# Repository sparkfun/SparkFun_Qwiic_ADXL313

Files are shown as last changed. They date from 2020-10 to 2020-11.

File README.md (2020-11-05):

SparkFun 3-Axis Digital Accelerometer Breakout - ADXL313 (Qwiic)
========================================

SparkFun 3-Axis Digital Accelerometer Breakout - ADXL313 (Qwiic) (https://www.sparkfun.com/products/17241)

[*SparkFun 3-Axis Digital Accelerometer Breakout - ADXL313 (Qwiic) (SEN-17241)*](https://www.sparkfun.com/products/17241)

The ADXL313 is a low power, high resolution (up to 13-bits) 3-axis accelerometer for measurement up to ±4g. It measures the static acceleration of gravity in tilt-sensing applications, as well as dynamic acceleration resulting from motion or shock. Digital output data is formatted as 16-bit twos complement and is accessible through the on board Qwiic connectors (I<sup>2</sup>C) or SPI. Its high resolution and low noise enable resolution of inclination changes of as little as 0.1°, while a built-in FIFO facilitates using oversampling techniques to improve resolution to as little as 0.025° of inclination. The integrated 32-level FIFO can also be used to store data to minimize host processor intervention, resulting in reduced system power consumption. Additional low power modes enable intelligent motion-based power management with threshold sensing and active acceleration measurement at extremely low power dissipation. 

Getting the ADXL313 Qwiic breakout set-up is easy. Simply supply the accelerometer with power and communication via the Qwiic connector to your chosen Qwiic development board and you will be good to go. Example use cases for the ADXL313 from Analog Devices include car alarm, hill start aid (HSA) systems, electronic parking brakes, and data recorders applications  (black boxes).

Repository Contents
-------------------

* **/Hardware** - Eagle design files (.brd, .sch)
* **/Hardware/Production** - Production panel files (.brd)

Documentation
--------------
* **[Hookup Guide](https://learn.sparkfun.com/tutorials/sparkfun-qwiic-3-axis-accelerometer-adxl313-hookup-guide)** - Hookup guide for the SparkFun Qwiic 3-Axis Accelerometer (ADXL313)
* **[Product Repository](https://github.com/sparkfun/SparkFun_Qwiic_ADXL313)** - Main hardware repository (including schematic and board design files)

Product Versions
----------------
* [SEN-17241](https://www.sparkfun.com/products/17241)- v1.0, Initial Release

License Information
-------------------

This product is _**open source**_! 

Please review the LICENSE.md file for license information. 

If you have any questions or concerns on licensing, please contact technical support on our [SparkFun forums](https://forum.sparkfun.com/viewforum.php?f=152).

Distributed as-is; no warranty is given.

- Your friends at SparkFun.

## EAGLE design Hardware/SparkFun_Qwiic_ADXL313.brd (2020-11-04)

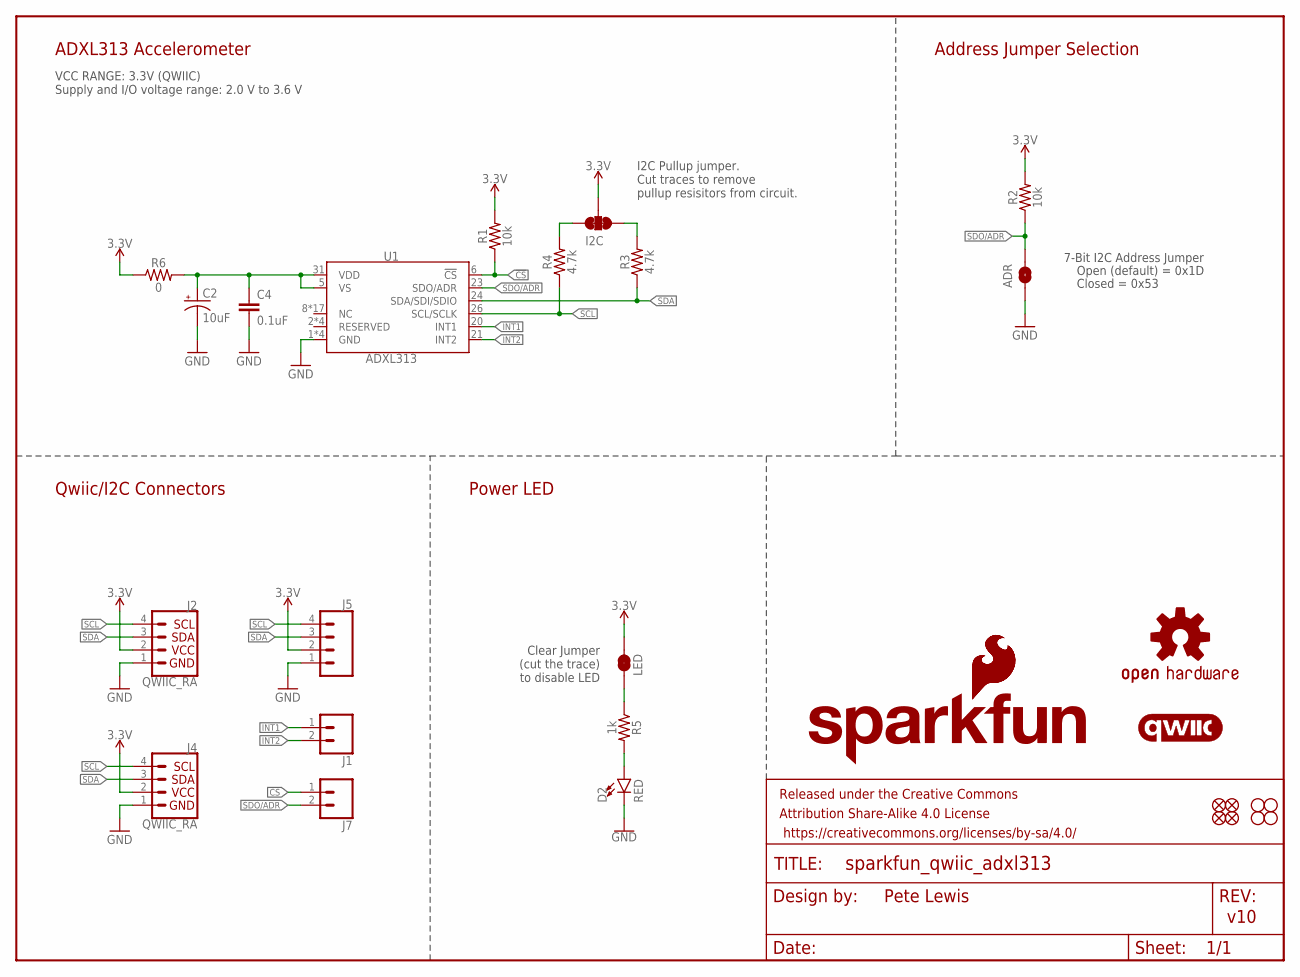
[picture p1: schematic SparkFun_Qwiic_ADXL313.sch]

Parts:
ADR: JUMPER-SMT_2_NO_SILK; SMT-JUMPER_2_NO_SILK
C2: 10uF; EIA3216
C4: 0.1uF; 0603
D2: RED; LED-0603
FRAME1: FRAME-LETTER; CREATIVE_COMMONS
I2C: JUMPER-SMT_3_2-NC_TRACE_SILK; SMT-JUMPER_3_2-NC_TRACE_SILK
J1, J7: CONN_021X02_NO_SILK; 1X02_NO_SILK
J2, J4: QWIIC_RA; JST04_1MM_RA
J5: CONN_041X04_NO_SILK; 1X04_NO_SILK
JP1: LED; SMT-JUMPER_2_NC_TRACE_SILK
JP2, JP5, JP6, JP11: FIDUCIALUFIDUCIAL; MICRO-FIDUCIAL
JP3, JP4, JP8, JP9: STAND-OFF
LOGO1: OSHW-LOGOMINI; OSHW-LOGO-MINI
LOGO2: SFE_LOGO_NAME_FLAME.1_INCH; SFE_LOGO_NAME_FLAME_.1
LOGO3: SFE_LOGO_FLAME.1_INCH; SFE_LOGO_FLAME_.1
LOGO4: QWIIC_LOGO_5MM; QWIIC_5MM
R1, R2: 10k; 0603
R3, R4: 4.7k; 0603
R5: 1k; 0603
R6: 0; 0603
U1: ADXL313; LFCSP

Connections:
3.3V: I2C.2, J2.2, J4.2, J5.2, JP1.2, R1.2, R2.2, R6.1
!CS: J7.1, R1.1, U1.6 (!CS)
GND: ADR.1, C2.C (-), C4.2, D2.C, J2.1, J4.1, J5.1, U1.1 (GND), U1.3 (GND), U1.4 (GND), U1.EPAD (GND)
INT1: J1.1, U1.20 (INT1)
INT2: J1.2, U1.21 (INT2)
unnamed: I2C.1, R3.2
unnamed: I2C.3, R4.2
unnamed: C2.A (+), C4.1, R6.2, U1.5 (VS), U1.31 (VDD)
unnamed: D2.A, R5.2
unnamed: JP1.1, R5.1
SCL: J2.4, J4.4, J5.4, R4.1, U1.26 (SCL/SCLK)
SDA: J2.3, J4.3, J5.3, R3.1, U1.24 (SDA/SDI/SDIO)
SDO/ADR: ADR.2, J7.2, R2.1, U1.23 (SDO/ADR)

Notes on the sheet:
7-Bit I2C Address Jumper
Closed = 0x53
Open (default) = 0x1D
Pete Lewis
v10
ADXL313 Accelerometer
Qwiic/I2C Connectors
I2C Pullup jumper. Cut traces to remove pullup resisitors from circuit.
Clear Jumper (cut the trace) to disable LED
Power LED
Address Jumper Selection
VCC RANGE: 3.3V (QWIIC) Supply and I/O voltage range: 2.0 V to 3.6 V

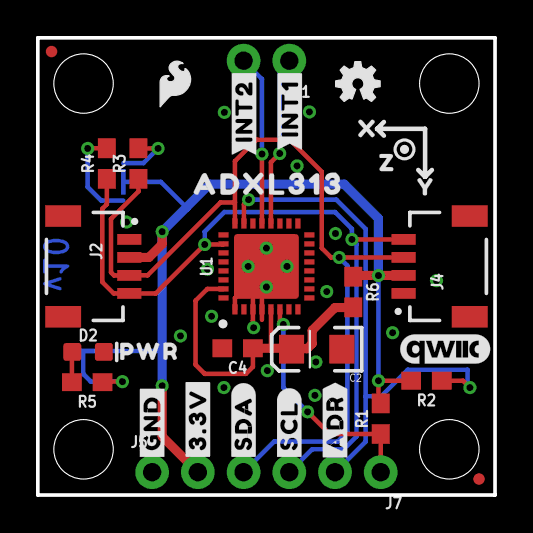
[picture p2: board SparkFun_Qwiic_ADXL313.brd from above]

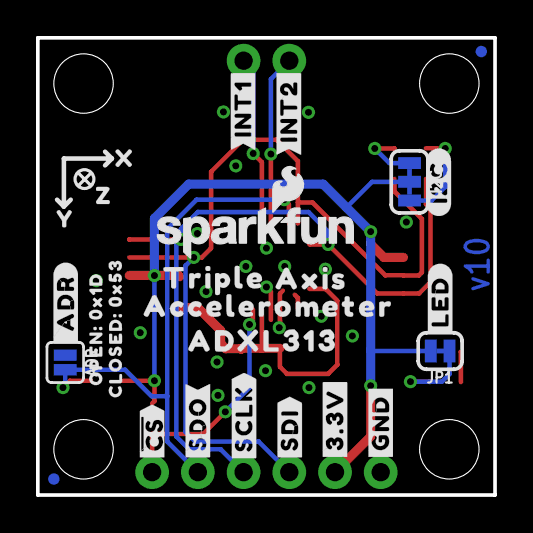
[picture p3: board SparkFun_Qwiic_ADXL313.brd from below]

Board: 2 copper layers, 25.4 x 25.4 mm, 63 parts (26 on the bottom side), 13 nets.

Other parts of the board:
U$1: TRIPLE0
U$2: AXIS0
U$3: ACCELEROMETER0
U$4, U$19: ADXL3130
U$5, U$6: #GND#0
U$7, U$8: #3#3V#0
U$9: #SDA#0
U$10: #SDI#0
U$11: #SCL#0
U$12: #_ADR#0
U$13, U$14: #INT2#0
U$15, U$16: #INT1#0
U$17, U$21: X0
U$18: ##CS##0
U$20: #SCLK#0
U$22: OPEN#_0X1D0
U$23: CLOSED#_0X530
U$24: #LED#0
U$25: PWR0
U$26, U$29: Y0
U$27: #I2C#0
U$28: #ADR#0
U$30: #SDO#0
U$31, U$32: Z0

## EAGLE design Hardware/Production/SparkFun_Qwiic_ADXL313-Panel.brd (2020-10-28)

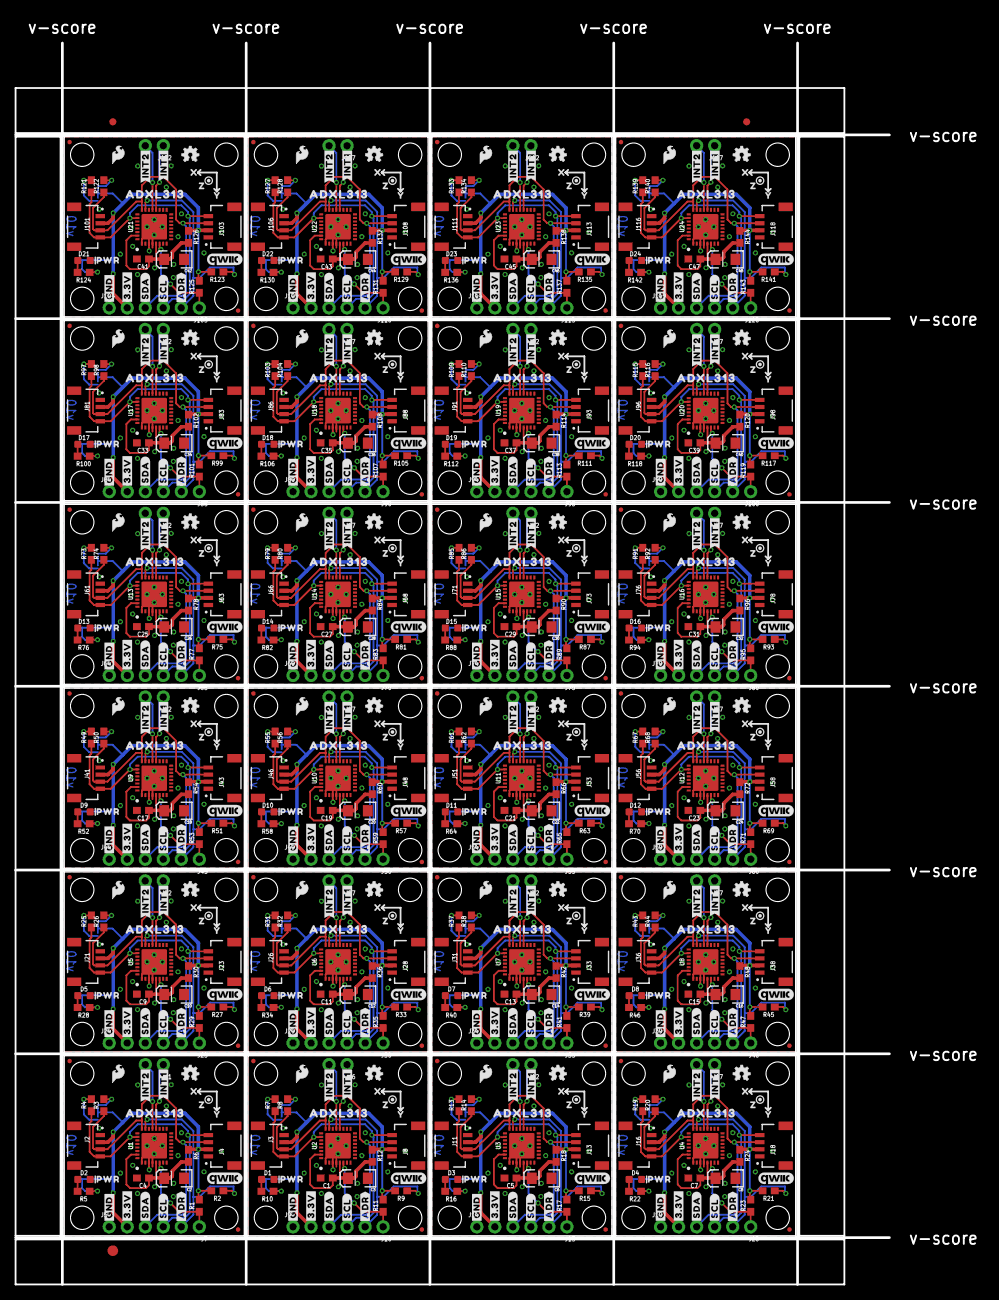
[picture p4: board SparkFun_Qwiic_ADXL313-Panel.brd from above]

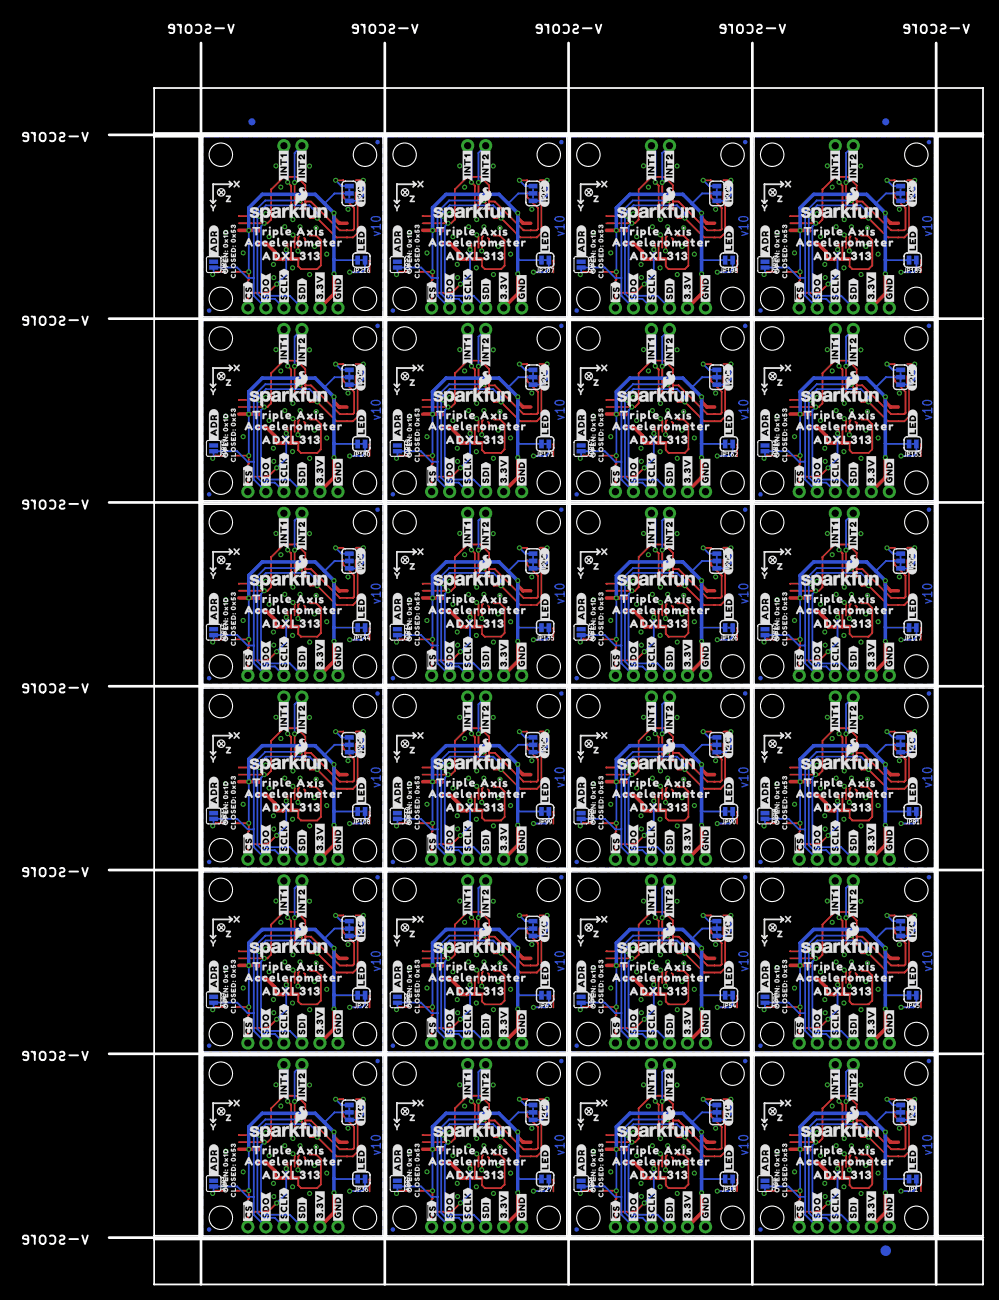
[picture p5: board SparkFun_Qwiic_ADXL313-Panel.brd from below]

Board: 2 copper layers, 123.2 x 175.0 mm, 1494 parts (627 on the bottom side), 312 nets.

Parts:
ADR, ADR1, ADR2, ADR3, ADR4, ADR5, ADR6, ADR7, ADR8, ADR9, ADR10, ADR11, ADR12, ADR13, ADR14, ADR15, ADR16, ADR17, ADR18, ADR19, ADR20, ADR21, ADR22, ADR23: SMT-JUMPER_2_NO_SILK
C1, C4, C5, C7, C9, C11, C13, C15, C17, C19, C21, C23, C25, C27, C29, C31, C33, C35, C37, C39, C41, C43, C45, C47: 0.1uF; 0603
C2, C3, C6, C8, C10, C12, C14, C16, C18, C20, C22, C24, C26, C28, C30, C32, C34, C36, C38, C40, C42, C44, C46, C48: 10uF; EIA3216
D1, D2, D3, D4, D5, D6, D7, D8, D9, D10, D11, D12, D13, D14, D15, D16, D17, D18, D19, D20, D21, D22, D23, D24: RED; LED-0603
E$1, E$2, E$3, E$4: FIDUCIAL-1X2
E$5, E$6: FIDUCIAL-1.5X3
I2C, I2C1, I2C2, I2C3, I2C4, I2C5, I2C6, I2C7, I2C8, I2C9, I2C10, I2C11, I2C12, I2C13, I2C14, I2C15, I2C16, I2C17, I2C18, I2C19, I2C20, I2C21, I2C22, I2C23: SMT-JUMPER_3_2-NC_TRACE_SILK
J1, J6, J7, J10, J12, J15, J17, J20, J22, J25, J27, J30, J32, J35, J37, J40, J42, J45, J47, J50, J52, J55, J57, J60, J62, J65, J67, J70, J72, J75, J77, J80, J82, J85, J87, J90, J92, J95, J97, J100, J102, J105, J107, J110, J112, J115, J117, J120: 1X02_NO_SILK
J2, J3, J4, J8, J11, J13, J16, J18, J21, J23, J26, J28, J31, J33, J36, J38, J41, J43, J46, J48, J51, J53, J56, J58, J61, J63, J66, J68, J71, J73, J76, J78, J81, J83, J86, J88, J91, J93, J96, J98, J101, J103, J106, J108, J111, J113, J116, J118: QWIIC_RA; JST04_1MM_RA
J5, J9, J14, J19, J24, J29, J34, J39, J44, J49, J54, J59, J64, J69, J74, J79, J84, J89, J94, J99, J104, J109, J114, J119: 1X04_NO_SILK
JP1, JP18, JP27, JP36, JP45, JP54, JP63, JP72, JP81, JP90, JP99, JP108, JP117, JP126, JP135, JP144, JP153, JP162, JP171, JP180, JP189, JP198, JP207, JP216: LED; SMT-JUMPER_2_NC_TRACE_SILK
JP2, JP5, JP6, JP11, JP12, JP13, JP14, JP15, JP21, JP22, JP23, JP24, JP30, JP31, JP32, JP33, JP39, JP40, JP41, JP42, JP48, JP49, JP50, JP51, JP57, JP58, JP59, JP60, JP66, JP67, JP68, JP69, JP75, JP76, JP77, JP78, JP84, JP85, JP86, JP87, JP93, JP94, JP95, JP96, JP102, JP103, JP104, JP105, JP111, JP112, JP113, JP114, JP120, JP121, JP122, JP123, JP129, JP130, JP131, JP132, JP138, JP139, JP140, JP141, JP147, JP148, JP149, JP150, JP156, JP157, JP158, JP159, JP165, JP166, JP167, JP168, JP174, JP175, JP176, JP177, JP183, JP184, JP185, JP186, JP192, JP193, JP194, JP195, JP201, JP202, JP203, JP204, JP210, JP211, JP212, JP213: FIDUCIALUFIDUCIAL; MICRO-FIDUCIAL
JP3, JP4, JP7, JP8, JP9, JP10, JP16, JP17, JP19, JP20, JP25, JP26, JP28, JP29, JP34, JP35, JP37, JP38, JP43, JP44, JP46, JP47, JP52, JP53, JP55, JP56, JP61, JP62, JP64, JP65, JP70, JP71, JP73, JP74, JP79, JP80, JP82, JP83, JP88, JP89, JP91, JP92, JP97, JP98, JP100, JP101, JP106, JP107, JP109, JP110, JP115, JP116, JP118, JP119, JP124, JP125, JP127, JP128, JP133, JP134, JP136, JP137, JP142, JP143, JP145, JP146, JP151, JP152, JP154, JP155, JP160, JP161, JP163, JP164, JP169, JP170, JP172, JP173, JP178, JP179, JP181, JP182, JP187, JP188, JP190, JP191, JP196, JP197, JP199, JP200, JP205, JP206, JP208, JP209, JP214, JP215: STAND-OFF
LOGO1, LOGO5, LOGO9, LOGO13, LOGO17, LOGO21, LOGO25, LOGO29, LOGO33, LOGO37, LOGO41, LOGO45, LOGO49, LOGO53, LOGO57, LOGO61, LOGO65, LOGO69, LOGO73, LOGO77, LOGO81, LOGO85, LOGO89, LOGO93: OSHW-LOGOMINI; OSHW-LOGO-MINI
LOGO2, LOGO6, LOGO10, LOGO14, LOGO18, LOGO22, LOGO26, LOGO30, LOGO34, LOGO38, LOGO42, LOGO46, LOGO50, LOGO54, LOGO58, LOGO62, LOGO66, LOGO70, LOGO74, LOGO78, LOGO82, LOGO86, LOGO90, LOGO94: SFE_LOGO_NAME_FLAME.1_INCH; SFE_LOGO_NAME_FLAME_.1
LOGO3, LOGO8, LOGO12, LOGO16, LOGO20, LOGO24, LOGO28, LOGO32, LOGO36, LOGO40, LOGO44, LOGO48, LOGO52, LOGO56, LOGO60, LOGO64, LOGO68, LOGO72, LOGO76, LOGO80, LOGO84, LOGO88, LOGO92, LOGO96: SFE_LOGO_FLAME.1_INCH; SFE_LOGO_FLAME_.1
LOGO4, LOGO7, LOGO11, LOGO15, LOGO19, LOGO23, LOGO27, LOGO31, LOGO35, LOGO39, LOGO43, LOGO47, LOGO51, LOGO55, LOGO59, LOGO63, LOGO67, LOGO71, LOGO75, LOGO79, LOGO83, LOGO87, LOGO91, LOGO95: QWIIC_LOGO_5MM; QWIIC_5MM
R1, R2, R9, R11, R15, R17, R21, R23, R27, R29, R33, R35, R39, R41, R45, R47, R51, R53, R57, R59, R63, R65, R69, R71, R75, R77, R81, R83, R87, R89, R93, R95, R99, R101, R105, R107, R111, R113, R117, R119, R123, R125, R129, R131, R135, R137, R141, R143: 10k; 0603
R3, R4, R7, R8, R13, R14, R19, R20, R25, R26, R31, R32, R37, R38, R43, R44, R49, R50, R55, R56, R61, R62, R67, R68, R73, R74, R79, R80, R85, R86, R91, R92, R97, R98, R103, R104, R109, R110, R115, R116, R121, R122, R127, R128, R133, R134, R139, R140: 4.7k; 0603
R5, R10, R16, R22, R28, R34, R40, R46, R52, R58, R64, R70, R76, R82, R88, R94, R100, R106, R112, R118, R124, R130, R136, R142: 1k; 0603
R6, R12, R18, R24, R30, R36, R42, R48, R54, R60, R66, R72, R78, R84, R90, R96, R102, R108, R114, R120, R126, R132, R138, R144: 0; 0603
U1, U2, U3, U4, U5, U6, U7, U8, U9, U10, U11, U12, U13, U14, U15, U16, U17, U18, U19, U20, U21, U22, U23, U24: ADXL313; LFCSP
U$1, U$33, U$65, U$97, U$129, U$161, U$193, U$225, U$257, U$289, U$321, U$353, U$385, U$417, U$449, U$481, U$513, U$545, U$577, U$609, U$641, U$673, U$705, U$737: TRIPLE0
U$2, U$34, U$66, U$98, U$130, U$162, U$194, U$226, U$258, U$290, U$322, U$354, U$386, U$418, U$450, U$482, U$514, U$546, U$578, U$610, U$642, U$674, U$706, U$738: AXIS0
U$3, U$35, U$67, U$99, U$131, U$163, U$195, U$227, U$259, U$291, U$323, U$355, U$387, U$419, U$451, U$483, U$515, U$547, U$579, U$611, U$643, U$675, U$707, U$739: ACCELEROMETER0
U$4, U$19, U$36, U$52, U$68, U$84, U$100, U$116, U$132, U$148, U$164, U$180, U$196, U$212, U$228, U$244, U$260, U$276, U$292, U$308, U$324, U$340, U$356, U$372, U$388, U$404, U$420, U$436, U$452, U$468, U$484, U$500, U$516, U$532, U$548, U$564, U$580, U$596, U$612, U$628, U$644, U$660, U$676, U$692, U$708, U$724, U$740, U$756: ADXL3130
U$5, U$6, U$37, U$38, U$69, U$70, U$101, U$102, U$133, U$134, U$165, U$166, U$197, U$198, U$229, U$230, U$261, U$262, U$293, U$294, U$325, U$326, U$357, U$358, U$389, U$390, U$421, U$422, U$453, U$454, U$485, U$486, U$517, U$518, U$549, U$550, U$581, U$582, U$613, U$614, U$645, U$646, U$677, U$678, U$709, U$710, U$741, U$742: #GND#0
U$7, U$8, U$39, U$40, U$71, U$72, U$103, U$104, U$135, U$136, U$167, U$168, U$199, U$200, U$231, U$232, U$263, U$264, U$295, U$296, U$327, U$328, U$359, U$360, U$391, U$392, U$423, U$424, U$455, U$456, U$487, U$488, U$519, U$520, U$551, U$552, U$583, U$584, U$615, U$616, U$647, U$648, U$679, U$680, U$711, U$712, U$743, U$744: #3#3V#0
U$9, U$41, U$73, U$105, U$137, U$169, U$201, U$233, U$265, U$297, U$329, U$361, U$393, U$425, U$457, U$489, U$521, U$553, U$585, U$617, U$649, U$681, U$713, U$745: #SDA#0
U$10, U$56, U$88, U$120, U$152, U$184, U$216, U$248, U$280, U$312, U$344, U$376, U$408, U$440, U$472, U$504, U$536, U$568, U$600, U$632, U$664, U$696, U$728, U$760: #SDI#0
U$11, U$42, U$74, U$106, U$138, U$170, U$202, U$234, U$266, U$298, U$330, U$362, U$394, U$426, U$458, U$490, U$522, U$554, U$586, U$618, U$650, U$682, U$714, U$746: #SCL#0
U$12, U$58, U$90, U$122, U$154, U$186, U$218, U$250, U$282, U$314, U$346, U$378, U$410, U$442, U$474, U$506, U$538, U$570, U$602, U$634, U$666, U$698, U$730, U$762: #_ADR#0
U$13, U$14, U$43, U$44, U$75, U$76, U$107, U$108, U$139, U$140, U$171, U$172, U$203, U$204, U$235, U$236, U$267, U$268, U$299, U$300, U$331, U$332, U$363, U$364, U$395, U$396, U$427, U$428, U$459, U$460, U$491, U$492, U$523, U$524, U$555, U$556, U$587, U$588, U$619, U$620, U$651, U$652, U$683, U$684, U$715, U$716, U$747, U$748: #INT2#0
U$15, U$16, U$45, U$46, U$77, U$78, U$109, U$110, U$141, U$142, U$173, U$174, U$205, U$206, U$237, U$238, U$269, U$270, U$301, U$302, U$333, U$334, U$365, U$366, U$397, U$398, U$429, U$430, U$461, U$462, U$493, U$494, U$525, U$526, U$557, U$558, U$589, U$590, U$621, U$622, U$653, U$654, U$685, U$686, U$717, U$718, U$749, U$750: #INT1#0
U$17, U$21, U$59, U$60, U$91, U$92, U$123, U$124, U$155, U$156, U$187, U$188, U$219, U$220, U$251, U$252, U$283, U$284, U$315, U$316, U$347, U$348, U$379, U$380, U$411, U$412, U$443, U$444, U$475, U$476, U$507, U$508, U$539, U$540, U$571, U$572, U$603, U$604, U$635, U$636, U$667, U$668, U$699, U$700, U$731, U$732, U$763, U$764: X0
U$18, U$47, U$79, U$111, U$143, U$175, U$207, U$239, U$271, U$303, U$335, U$367, U$399, U$431, U$463, U$495, U$527, U$559, U$591, U$623, U$655, U$687, U$719, U$751: ##CS##0
U$20, U$57, U$89, U$121, U$153, U$185, U$217, U$249, U$281, U$313, U$345, U$377, U$409, U$441, U$473, U$505, U$537, U$569, U$601, U$633, U$665, U$697, U$729, U$761: #SCLK#0
U$22, U$48, U$80, U$112, U$144, U$176, U$208, U$240, U$272, U$304, U$336, U$368, U$400, U$432, U$464, U$496, U$528, U$560, U$592, U$624, U$656, U$688, U$720, U$752: OPEN#_0X1D0
U$23, U$49, U$81, U$113, U$145, U$177, U$209, U$241, U$273, U$305, U$337, U$369, U$401, U$433, U$465, U$497, U$529, U$561, U$593, U$625, U$657, U$689, U$721, U$753: CLOSED#_0X530
U$24, U$50, U$82, U$114, U$146, U$178, U$210, U$242, U$274, U$306, U$338, U$370, U$402, U$434, U$466, U$498, U$530, U$562, U$594, U$626, U$658, U$690, U$722, U$754: #LED#0
U$25, U$51, U$83, U$115, U$147, U$179, U$211, U$243, U$275, U$307, U$339, U$371, U$403, U$435, U$467, U$499, U$531, U$563, U$595, U$627, U$659, U$691, U$723, U$755: PWR0
U$26, U$29, U$61, U$62, U$93, U$94, U$125, U$126, U$157, U$158, U$189, U$190, U$221, U$222, U$253, U$254, U$285, U$286, U$317, U$318, U$349, U$350, U$381, U$382, U$413, U$414, U$445, U$446, U$477, U$478, U$509, U$510, U$541, U$542, U$573, U$574, U$605, U$606, U$637, U$638, U$669, U$670, U$701, U$702, U$733, U$734, U$765, U$766: Y0
U$27, U$53, U$85, U$117, U$149, U$181, U$213, U$245, U$277, U$309, U$341, U$373, U$405, U$437, U$469, U$501, U$533, U$565, U$597, U$629, U$661, U$693, U$725, U$757: #I2C#0
U$28, U$55, U$87, U$119, U$151, U$183, U$215, U$247, U$279, U$311, U$343, U$375, U$407, U$439, U$471, U$503, U$535, U$567, U$599, U$631, U$663, U$695, U$727, U$759: #ADR#0
U$30, U$54, U$86, U$118, U$150, U$182, U$214, U$246, U$278, U$310, U$342, U$374, U$406, U$438, U$470, U$502, U$534, U$566, U$598, U$630, U$662, U$694, U$726, U$758: #SDO#0
U$31, U$32, U$63, U$64, U$95, U$96, U$127, U$128, U$159, U$160, U$191, U$192, U$223, U$224, U$255, U$256, U$287, U$288, U$319, U$320, U$351, U$352, U$383, U$384, U$415, U$416, U$447, U$448, U$479, U$480, U$511, U$512, U$543, U$544, U$575, U$576, U$607, U$608, U$639, U$640, U$671, U$672, U$703, U$704, U$735, U$736, U$767, U$768: Z0

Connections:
3.3V: I2C.2, J2.2, J4.2, J5.2, JP1.2, R1.2, R2.2, R6.1
3.3V1: I2C1.2, J3.2, J8.2, J9.2, JP18.2, R9.2, R11.2, R12.1
3.3V2: I2C2.2, J11.2, J13.2, J14.2, JP27.2, R15.2, R17.2, R18.1
3.3V3: I2C3.2, J16.2, J18.2, J19.2, JP36.2, R21.2, R23.2, R24.1
3.3V4: I2C4.2, J21.2, J23.2, J24.2, JP45.2, R27.2, R29.2, R30.1
3.3V5: I2C5.2, J26.2, J28.2, J29.2, JP54.2, R33.2, R35.2, R36.1
3.3V6: I2C6.2, J31.2, J33.2, J34.2, JP63.2, R39.2, R41.2, R42.1
3.3V7: I2C7.2, J36.2, J38.2, J39.2, JP72.2, R45.2, R47.2, R48.1
3.3V8: I2C8.2, J41.2, J43.2, J44.2, JP81.2, R51.2, R53.2, R54.1
3.3V9: I2C9.2, J46.2, J48.2, J49.2, JP90.2, R57.2, R59.2, R60.1
3.3V10: I2C10.2, J51.2, J53.2, J54.2, JP99.2, R63.2, R65.2, R66.1
3.3V11: I2C11.2, J56.2, J58.2, J59.2, JP108.2, R69.2, R71.2, R72.1
3.3V12: I2C12.2, J61.2, J63.2, J64.2, JP117.2, R75.2, R77.2, R78.1
3.3V13: I2C13.2, J66.2, J68.2, J69.2, JP126.2, R81.2, R83.2, R84.1
3.3V14: I2C14.2, J71.2, J73.2, J74.2, JP135.2, R87.2, R89.2, R90.1
3.3V15: I2C15.2, J76.2, J78.2, J79.2, JP144.2, R93.2, R95.2, R96.1
3.3V16: I2C16.2, J81.2, J83.2, J84.2, JP153.2, R99.2, R101.2, R102.1
3.3V17: I2C17.2, J86.2, J88.2, J89.2, JP162.2, R105.2, R107.2, R108.1
3.3V18: I2C18.2, J91.2, J93.2, J94.2, JP171.2, R111.2, R113.2, R114.1
3.3V19: I2C19.2, J96.2, J98.2, J99.2, JP180.2, R117.2, R119.2, R120.1
3.3V20: I2C20.2, J101.2, J103.2, J104.2, JP189.2, R123.2, R125.2, R126.1
3.3V21: I2C21.2, J106.2, J108.2, J109.2, JP198.2, R129.2, R131.2, R132.1
3.3V22: I2C22.2, J111.2, J113.2, J114.2, JP207.2, R135.2, R137.2, R138.1
3.3V23: I2C23.2, J116.2, J118.2, J119.2, JP216.2, R141.2, R143.2, R144.1
!CS: J7.1, R1.1, U1.6
!CS1: J10.1, R11.1, U2.6
!CS2: J15.1, R17.1, U3.6
!CS3: J20.1, R23.1, U4.6
!CS4: J25.1, R29.1, U5.6
!CS5: J30.1, R35.1, U6.6
!CS6: J35.1, R41.1, U7.6
!CS7: J40.1, R47.1, U8.6
!CS8: J45.1, R53.1, U9.6
!CS9: J50.1, R59.1, U10.6
!CS10: J55.1, R65.1, U11.6
!CS11: J60.1, R71.1, U12.6
!CS12: J65.1, R77.1, U13.6
!CS13: J70.1, R83.1, U14.6
!CS14: J75.1, R89.1, U15.6
!CS15: J80.1, R95.1, U16.6
!CS16: J85.1, R101.1, U17.6
!CS17: J90.1, R107.1, U18.6
!CS18: J95.1, R113.1, U19.6
!CS19: J100.1, R119.1, U20.6
!CS20: J105.1, R125.1, U21.6
!CS21: J110.1, R131.1, U22.6
!CS22: J115.1, R137.1, U23.6
!CS23: J120.1, R143.1, U24.6
GND: ADR.1, C2.C, C4.2, D2.C, J2.1, J4.1, J5.1, U1.1, U1.3, U1.4, U1.EPAD
GND1: ADR1.1, C1.2, C3.C, D1.C, J3.1, J8.1, J9.1, U2.1, U2.3, U2.4, U2.EPAD
GND2: ADR2.1, C5.2, C6.C, D3.C, J11.1, J13.1, J14.1, U3.1, U3.3, U3.4, U3.EPAD
GND3: ADR3.1, C7.2, C8.C, D4.C, J16.1, J18.1, J19.1, U4.1, U4.3, U4.4, U4.EPAD
GND4: ADR4.1, C9.2, C10.C, D5.C, J21.1, J23.1, J24.1, U5.1, U5.3, U5.4, U5.EPAD
GND5: ADR5.1, C11.2, C12.C, D6.C, J26.1, J28.1, J29.1, U6.1, U6.3, U6.4, U6.EPAD
GND6: ADR6.1, C13.2, C14.C, D7.C, J31.1, J33.1, J34.1, U7.1, U7.3, U7.4, U7.EPAD
GND7: ADR7.1, C15.2, C16.C, D8.C, J36.1, J38.1, J39.1, U8.1, U8.3, U8.4, U8.EPAD
GND8: ADR8.1, C17.2, C18.C, D9.C, J41.1, J43.1, J44.1, U9.1, U9.3, U9.4, U9.EPAD
GND9: ADR9.1, C19.2, C20.C, D10.C, J46.1, J48.1, J49.1, U10.1, U10.3, U10.4, U10.EPAD
GND10: ADR10.1, C21.2, C22.C, D11.C, J51.1, J53.1, J54.1, U11.1, U11.3, U11.4, U11.EPAD
GND11: ADR11.1, C23.2, C24.C, D12.C, J56.1, J58.1, J59.1, U12.1, U12.3, U12.4, U12.EPAD
GND12: ADR12.1, C25.2, C26.C, D13.C, J61.1, J63.1, J64.1, U13.1, U13.3, U13.4, U13.EPAD
GND13: ADR13.1, C27.2, C28.C, D14.C, J66.1, J68.1, J69.1, U14.1, U14.3, U14.4, U14.EPAD
GND14: ADR14.1, C29.2, C30.C, D15.C, J71.1, J73.1, J74.1, U15.1, U15.3, U15.4, U15.EPAD
GND15: ADR15.1, C31.2, C32.C, D16.C, J76.1, J78.1, J79.1, U16.1, U16.3, U16.4, U16.EPAD
GND16: ADR16.1, C33.2, C34.C, D17.C, J81.1, J83.1, J84.1, U17.1, U17.3, U17.4, U17.EPAD
GND17: ADR17.1, C35.2, C36.C, D18.C, J86.1, J88.1, J89.1, U18.1, U18.3, U18.4, U18.EPAD
GND18: ADR18.1, C37.2, C38.C, D19.C, J91.1, J93.1, J94.1, U19.1, U19.3, U19.4, U19.EPAD
GND19: ADR19.1, C39.2, C40.C, D20.C, J96.1, J98.1, J99.1, U20.1, U20.3, U20.4, U20.EPAD
GND20: ADR20.1, C41.2, C42.C, D21.C, J101.1, J103.1, J104.1, U21.1, U21.3, U21.4, U21.EPAD
GND21: ADR21.1, C43.2, C44.C, D22.C, J106.1, J108.1, J109.1, U22.1, U22.3, U22.4, U22.EPAD
GND22: ADR22.1, C45.2, C46.C, D23.C, J111.1, J113.1, J114.1, U23.1, U23.3, U23.4, U23.EPAD
GND23: ADR23.1, C47.2, C48.C, D24.C, J116.1, J118.1, J119.1, U24.1, U24.3, U24.4, U24.EPAD
INT1: J1.1, U1.20
INT2: J1.2, U1.21
INT3: J6.2, U2.21
INT4: J6.1, U2.20
INT5: J12.2, U3.21
INT6: J12.1, U3.20
INT7: J17.2, U4.21
INT8: J17.1, U4.20
INT9: J22.2, U5.21
INT10: J22.1, U5.20
INT11: J27.2, U6.21
INT12: J27.1, U6.20
INT13: J32.2, U7.21
INT14: J32.1, U7.20
INT15: J37.2, U8.21
INT16: J37.1, U8.20
INT17: J42.2, U9.21
INT18: J42.1, U9.20
INT19: J47.2, U10.21
INT20: J47.1, U10.20
INT21: J52.2, U11.21
INT22: J52.1, U11.20
INT23: J57.2, U12.21
INT24: J57.1, U12.20
INT25: J62.2, U13.21
INT26: J62.1, U13.20
INT27: J67.2, U14.21
INT28: J67.1, U14.20
INT29: J72.2, U15.21
INT30: J72.1, U15.20
INT31: J77.2, U16.21
INT32: J77.1, U16.20
INT33: J82.2, U17.21
INT34: J82.1, U17.20
INT35: J87.2, U18.21
INT36: J87.1, U18.20
INT37: J92.2, U19.21
INT38: J92.1, U19.20
INT39: J97.2, U20.21
INT40: J97.1, U20.20
INT41: J102.2, U21.21
INT42: J102.1, U21.20
INT43: J107.2, U22.21
INT44: J107.1, U22.20
INT45: J112.2, U23.21
INT46: J112.1, U23.20
INT47: J117.2, U24.21
INT48: J117.1, U24.20
unnamed: I2C.1, R3.2
unnamed: I2C.3, R4.2
unnamed: C2.A, C4.1, R6.2, U1.5, U1.31
unnamed: I2C1.1, R8.2
unnamed: I2C1.3, R7.2
unnamed: D2.A, R5.2
unnamed: D1.A, R10.2
unnamed: JP1.1, R5.1
unnamed: JP18.1, R10.1
unnamed: C1.1, C3.A, R12.2, U2.5, U2.31
unnamed: I2C2.1, R14.2
unnamed: I2C2.3, R13.2
unnamed: D3.A, R16.2
unnamed: JP27.1, R16.1
unnamed: C5.1, C6.A, R18.2, U3.5, U3.31
unnamed: I2C3.1, R20.2
unnamed: I2C3.3, R19.2
unnamed: D4.A, R22.2
unnamed: JP36.1, R22.1
unnamed: C7.1, C8.A, R24.2, U4.5, U4.31
unnamed: I2C4.1, R26.2
unnamed: I2C4.3, R25.2
unnamed: D5.A, R28.2
unnamed: JP45.1, R28.1
unnamed: C9.1, C10.A, R30.2, U5.5, U5.31
unnamed: I2C5.1, R32.2
unnamed: I2C5.3, R31.2
unnamed: D6.A, R34.2
unnamed: JP54.1, R34.1
unnamed: C11.1, C12.A, R36.2, U6.5, U6.31
unnamed: I2C6.1, R38.2
unnamed: I2C6.3, R37.2
unnamed: D7.A, R40.2
unnamed: JP63.1, R40.1
unnamed: C13.1, C14.A, R42.2, U7.5, U7.31
unnamed: I2C7.1, R44.2
unnamed: I2C7.3, R43.2
unnamed: D8.A, R46.2
unnamed: JP72.1, R46.1
unnamed: C15.1, C16.A, R48.2, U8.5, U8.31
unnamed: I2C8.1, R50.2
unnamed: I2C8.3, R49.2
unnamed: D9.A, R52.2
unnamed: JP81.1, R52.1
unnamed: C17.1, C18.A, R54.2, U9.5, U9.31
unnamed: I2C9.1, R56.2
unnamed: I2C9.3, R55.2
unnamed: D10.A, R58.2
unnamed: JP90.1, R58.1
unnamed: C19.1, C20.A, R60.2, U10.5, U10.31
unnamed: I2C10.1, R62.2
unnamed: I2C10.3, R61.2
unnamed: D11.A, R64.2
unnamed: JP99.1, R64.1
unnamed: C21.1, C22.A, R66.2, U11.5, U11.31
unnamed: I2C11.1, R68.2
unnamed: I2C11.3, R67.2
unnamed: D12.A, R70.2
unnamed: JP108.1, R70.1
unnamed: C23.1, C24.A, R72.2, U12.5, U12.31
unnamed: I2C12.1, R74.2
unnamed: I2C12.3, R73.2
unnamed: D13.A, R76.2
unnamed: JP117.1, R76.1
unnamed: C25.1, C26.A, R78.2, U13.5, U13.31
unnamed: I2C13.1, R80.2
unnamed: I2C13.3, R79.2
unnamed: D14.A, R82.2
unnamed: JP126.1, R82.1
unnamed: C27.1, C28.A, R84.2, U14.5, U14.31
unnamed: I2C14.1, R86.2
unnamed: I2C14.3, R85.2
unnamed: D15.A, R88.2
unnamed: JP135.1, R88.1
unnamed: C29.1, C30.A, R90.2, U15.5, U15.31
unnamed: I2C15.1, R92.2
unnamed: I2C15.3, R91.2
unnamed: D16.A, R94.2
unnamed: JP144.1, R94.1
unnamed: C31.1, C32.A, R96.2, U16.5, U16.31
unnamed: I2C16.1, R98.2
unnamed: I2C16.3, R97.2
unnamed: D17.A, R100.2
unnamed: JP153.1, R100.1
unnamed: C33.1, C34.A, R102.2, U17.5, U17.31
unnamed: I2C17.1, R104.2
unnamed: I2C17.3, R103.2
unnamed: D18.A, R106.2
unnamed: JP162.1, R106.1
unnamed: C35.1, C36.A, R108.2, U18.5, U18.31
unnamed: I2C18.1, R110.2
unnamed: I2C18.3, R109.2
unnamed: D19.A, R112.2
unnamed: JP171.1, R112.1
unnamed: C37.1, C38.A, R114.2, U19.5, U19.31
unnamed: I2C19.1, R116.2
unnamed: I2C19.3, R115.2
unnamed: D20.A, R118.2
unnamed: JP180.1, R118.1
unnamed: C39.1, C40.A, R120.2, U20.5, U20.31
unnamed: I2C20.1, R122.2
unnamed: I2C20.3, R121.2
unnamed: D21.A, R124.2
unnamed: JP189.1, R124.1
unnamed: C41.1, C42.A, R126.2, U21.5, U21.31
unnamed: I2C21.1, R128.2
unnamed: I2C21.3, R127.2
unnamed: D22.A, R130.2
unnamed: JP198.1, R130.1
unnamed: C43.1, C44.A, R132.2, U22.5, U22.31
unnamed: I2C22.1, R134.2
unnamed: I2C22.3, R133.2
unnamed: D23.A, R136.2
unnamed: JP207.1, R136.1
unnamed: C45.1, C46.A, R138.2, U23.5, U23.31
unnamed: I2C23.1, R140.2
unnamed: I2C23.3, R139.2
unnamed: D24.A, R142.2
unnamed: JP216.1, R142.1
unnamed: C47.1, C48.A, R144.2, U24.5, U24.31
SCL: J2.4, J4.4, J5.4, R4.1, U1.26
SCL1: J3.4, J8.4, J9.4, R7.1, U2.26
SCL2: J11.4, J13.4, J14.4, R13.1, U3.26
SCL3: J16.4, J18.4, J19.4, R19.1, U4.26
SCL4: J21.4, J23.4, J24.4, R25.1, U5.26
SCL5: J26.4, J28.4, J29.4, R31.1, U6.26
SCL6: J31.4, J33.4, J34.4, R37.1, U7.26
SCL7: J36.4, J38.4, J39.4, R43.1, U8.26
SCL8: J41.4, J43.4, J44.4, R49.1, U9.26
SCL9: J46.4, J48.4, J49.4, R55.1, U10.26
SCL10: J51.4, J53.4, J54.4, R61.1, U11.26
SCL11: J56.4, J58.4, J59.4, R67.1, U12.26
SCL12: J61.4, J63.4, J64.4, R73.1, U13.26
SCL13: J66.4, J68.4, J69.4, R79.1, U14.26
SCL14: J71.4, J73.4, J74.4, R85.1, U15.26
SCL15: J76.4, J78.4, J79.4, R91.1, U16.26
SCL16: J81.4, J83.4, J84.4, R97.1, U17.26
SCL17: J86.4, J88.4, J89.4, R103.1, U18.26
SCL18: J91.4, J93.4, J94.4, R109.1, U19.26
SCL19: J96.4, J98.4, J99.4, R115.1, U20.26
SCL20: J101.4, J103.4, J104.4, R121.1, U21.26
SCL21: J106.4, J108.4, J109.4, R127.1, U22.26
SCL22: J111.4, J113.4, J114.4, R133.1, U23.26
SCL23: J116.4, J118.4, J119.4, R139.1, U24.26
SDA: J2.3, J4.3, J5.3, R3.1, U1.24
SDA1: J3.3, J8.3, J9.3, R8.1, U2.24
SDA2: J11.3, J13.3, J14.3, R14.1, U3.24
SDA3: J16.3, J18.3, J19.3, R20.1, U4.24
SDA4: J21.3, J23.3, J24.3, R26.1, U5.24
SDA5: J26.3, J28.3, J29.3, R32.1, U6.24
SDA6: J31.3, J33.3, J34.3, R38.1, U7.24
SDA7: J36.3, J38.3, J39.3, R44.1, U8.24
SDA8: J41.3, J43.3, J44.3, R50.1, U9.24
SDA9: J46.3, J48.3, J49.3, R56.1, U10.24
SDA10: J51.3, J53.3, J54.3, R62.1, U11.24
SDA11: J56.3, J58.3, J59.3, R68.1, U12.24
SDA12: J61.3, J63.3, J64.3, R74.1, U13.24
SDA13: J66.3, J68.3, J69.3, R80.1, U14.24
SDA14: J71.3, J73.3, J74.3, R86.1, U15.24
SDA15: J76.3, J78.3, J79.3, R92.1, U16.24
SDA16: J81.3, J83.3, J84.3, R98.1, U17.24
SDA17: J86.3, J88.3, J89.3, R104.1, U18.24
SDA18: J91.3, J93.3, J94.3, R110.1, U19.24
SDA19: J96.3, J98.3, J99.3, R116.1, U20.24
SDA20: J101.3, J103.3, J104.3, R122.1, U21.24
SDA21: J106.3, J108.3, J109.3, R128.1, U22.24
SDA22: J111.3, J113.3, J114.3, R134.1, U23.24
SDA23: J116.3, J118.3, J119.3, R140.1, U24.24
SDO/ADR: ADR.2, J7.2, R2.1, U1.23
SDO/ADR1: ADR1.2, J10.2, R9.1, U2.23
SDO/ADR2: ADR2.2, J15.2, R15.1, U3.23
SDO/ADR3: ADR3.2, J20.2, R21.1, U4.23
SDO/ADR4: ADR4.2, J25.2, R27.1, U5.23
SDO/ADR5: ADR5.2, J30.2, R33.1, U6.23
SDO/ADR6: ADR6.2, J35.2, R39.1, U7.23
SDO/ADR7: ADR7.2, J40.2, R45.1, U8.23
SDO/ADR8: ADR8.2, J45.2, R51.1, U9.23
SDO/ADR9: ADR9.2, J50.2, R57.1, U10.23
SDO/ADR10: ADR10.2, J55.2, R63.1, U11.23
SDO/ADR11: ADR11.2, J60.2, R69.1, U12.23
SDO/ADR12: ADR12.2, J65.2, R75.1, U13.23
SDO/ADR13: ADR13.2, J70.2, R81.1, U14.23
SDO/ADR14: ADR14.2, J75.2, R87.1, U15.23
SDO/ADR15: ADR15.2, J80.2, R93.1, U16.23
SDO/ADR16: ADR16.2, J85.2, R99.1, U17.23
SDO/ADR17: ADR17.2, J90.2, R105.1, U18.23
SDO/ADR18: ADR18.2, J95.2, R111.1, U19.23
SDO/ADR19: ADR19.2, J100.2, R117.1, U20.23
SDO/ADR20: ADR20.2, J105.2, R123.1, U21.23
SDO/ADR21: ADR21.2, J110.2, R129.1, U22.23
SDO/ADR22: ADR22.2, J115.2, R135.1, U23.23
SDO/ADR23: ADR23.2, J120.2, R141.1, U24.23

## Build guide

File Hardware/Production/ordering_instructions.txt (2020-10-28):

panel size, 117x162mm
PCB thickness, 1.6mm
number of layers, 2
soldermask color, Red
silkscreen color, White
oz copper, 1oz
finish, HASL lead free
stencils, top
pcs per panel, 24
min trace width, 0.2540mm / 0.0100in
min drill size, 0.3810mm / 0.0150in

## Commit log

2020-09-14 v01 sch import done. ready for layout
    [SparkFun_Qwiic_ADXL313.brd, SparkFun_Qwiic_ADXL313.sch]
2020-09-14 pullup on CS for default I2C mode (aka mode jumper)
    [SparkFun_Qwiic_ADXL313.brd, SparkFun_Qwiic_ADXL313.sch]
2020-09-14 routing done
    [SparkFun_Qwiic_ADXL313.brd, SparkFun_Qwiic_ADXL313.sch]
2020-09-15 ENG checklist run changes - pre-group review
    -sch cleanup
    -PROD_ID for IC
    -GND stiching vias and re-routed 3.3V near IC for better GND return path from filter caps
    -approve DRC errors (jumper overlaps and some stubs)
    -more measures
    [SparkFun_Qwiic_ADXL313.brd, SparkFun_Qwiic_ADXL313.sch]
2020-09-17 Group Review changes
    -Removed MODE Jumper, CS should always be tied high.
    -Added optional Resistor on power input to IC, for potential RC filter.
    -SDA/SCL corrected
    - corrected pin location in device footprint. (they were mirrored)
    - 3 vias under IC are now actually named GND
    - CS and SDO were swapped with INTs so all data lines are on the same row of headers
    - End caps on buzzards corrected.
    - Moved to all I2C labels on top and SPI labels on bottom.
    - added tRestrict near pads on IC to stop gdn flow on top corner and natural jumper of two inner GND pads.
    - Symbol now has NC pin and Reserved pin
    [SparkFun_Qwiic_ADXL313.brd, SparkFun_Qwiic_ADXL313.sch]
2020-09-18 More changes from review #2
    -INPUTS and OUTPUT silk flags corrected
    -XYZ axis silk rotated 90 degress to match IC axis. on both top and bottom silk.
    -Removed label on top silk for CS pin (because it's not part of I2C).
    -Swapped CD and ADR/SDO, so that all I2C pins are in a a row.
    -Changed ADR silk label on top so that it is an INPUT flag silk type
    -rotated I2C jumper (and silk) so that all bottom silk reads the same direction.
    [SparkFun_Qwiic_ADXL313.brd]
2020-09-18 DRC error approval
    [SparkFun_Qwiic_ADXL313.brd]
2020-09-21 Axis label correction
    -also updated xyz letters to buzzard text labels
    [SparkFun_Qwiic_ADXL313.brd, SparkFun_Qwiic_ADXL313.sch]
2020-09-21 ran checklist - moved one via to avoid silk label
    [SparkFun_Qwiic_ADXL313.brd]
2020-10-28 production panel files
    [SparkFun_Qwiic_ADXL313-Panel.GBL, SparkFun_Qwiic_ADXL313-Panel.GBP, SparkFun_Qwiic_ADXL313-Panel.GBS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]
2020-11-04 replaced ADXL313 with device in main eagle Sensor library
    [SparkFun_Qwiic_ADXL313.brd, SparkFun_Qwiic_ADXL313.sch]

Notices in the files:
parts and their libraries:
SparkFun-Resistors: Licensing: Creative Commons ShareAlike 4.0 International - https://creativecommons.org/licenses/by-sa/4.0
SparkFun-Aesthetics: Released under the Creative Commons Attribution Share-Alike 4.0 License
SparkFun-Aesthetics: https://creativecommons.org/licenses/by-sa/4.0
